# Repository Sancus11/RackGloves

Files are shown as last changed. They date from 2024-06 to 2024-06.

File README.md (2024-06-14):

# RackGloves

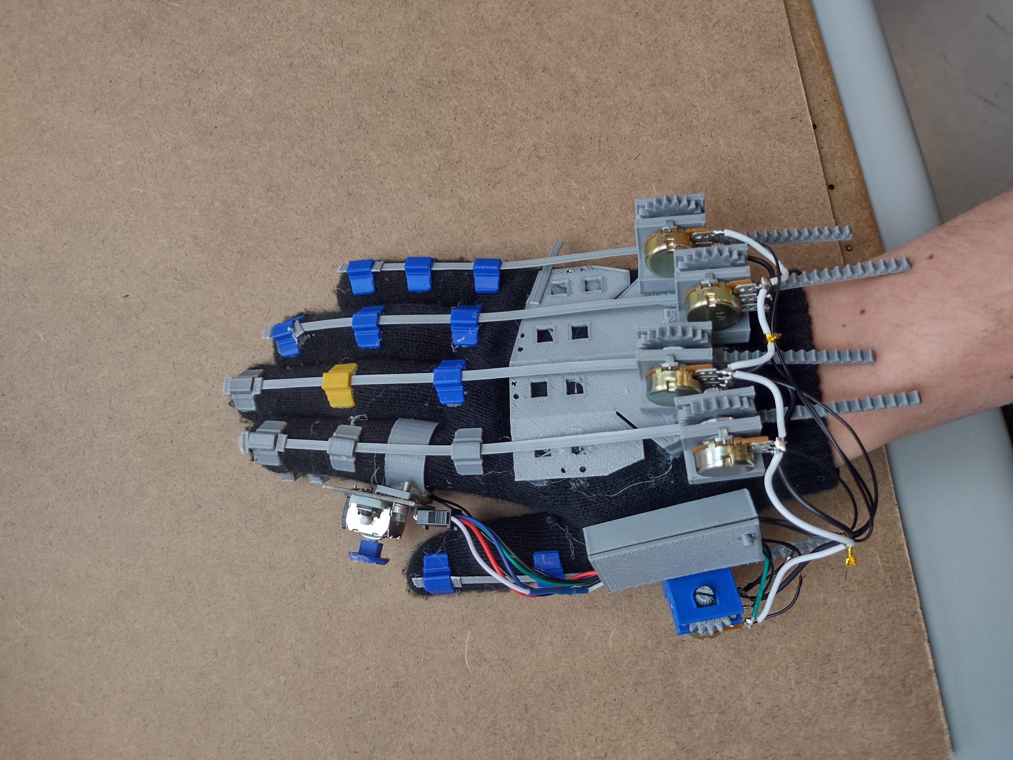
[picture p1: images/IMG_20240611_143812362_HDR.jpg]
image of the finished glove


Simple, cheap and, working glove harware for vr finger tracking using opengloves and lucidvr. This has the advantage of having the bare minimum of assembly and minimal parts that you may already have on hand. It works by a flexible strip on the back that has its horizontal motion actuate a rack on a pot. It uses version 3 of the software so tracking only. Only minimal assembly and parts needed.

Joystick ring mount, button mount, and esp32 case are also in this repo.

NOTE: things are currently in a beta state. May not work the best but it should get you from start to finish. Any improvements are welcome. See pull request for bata and incomplete additions 

# Build Guide

 We have a comprehensive [build guide](Build_Guide.md) and all the necessary stls here. Additional parts can be found from the [protoloves repo](https://github.com/Valsvirtuals/ProtoGlove) and from other [community designs](https://github.com/LucidVR/lucidgloves/wiki/Community-Design-List). 

# Software

Take the esp software from the [Lucidgloves repo](https://github.com/LucidVR/lucidgloves) and it will communicate with the [Opengloves software](https://github.com/LucidVR/opengloves-driver) for steam vr.

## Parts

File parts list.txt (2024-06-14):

for 1 hand
from proto glove
  1 thumb plate
  1 hand plate (modular)
  1 controller ring mount
  1 controller mount
  5 single point modular mounts

from this repo
for tracking fingers
rack units
  5 bodies
  5 racks
  5 fingerline
  5 spur gear
  14 guides (sewing or glue)

  non printed
  5 10k potentiometers

for espcase
  1 lid
  1 case
  1 button push

for buttons
  1 button baseplate
  2 button house

  non printed
  2 6mm pushbuttons 

for joystick
  1 joystick mount (may need adjusting)
  1 joystick ring (may need adjusting)
  1 joystick nub (may need adjusting)

  non printed
  5 pin female jst connector
  1 joystick unit

Needed tools to assemble
  Sandpaper
  3d printer
  Soldering station
  Wire
  hotglue
  Super glue
  Sewing thread and needle (optional)
  wd-40 
  Drill bits (optional)
  Twist ties

list of non 3d printed parts (duplicates in prior lists)
  2 6mm pushbuttons 
  5 10k potentiometers
  5 pin female jst connector
  1 joystick unit

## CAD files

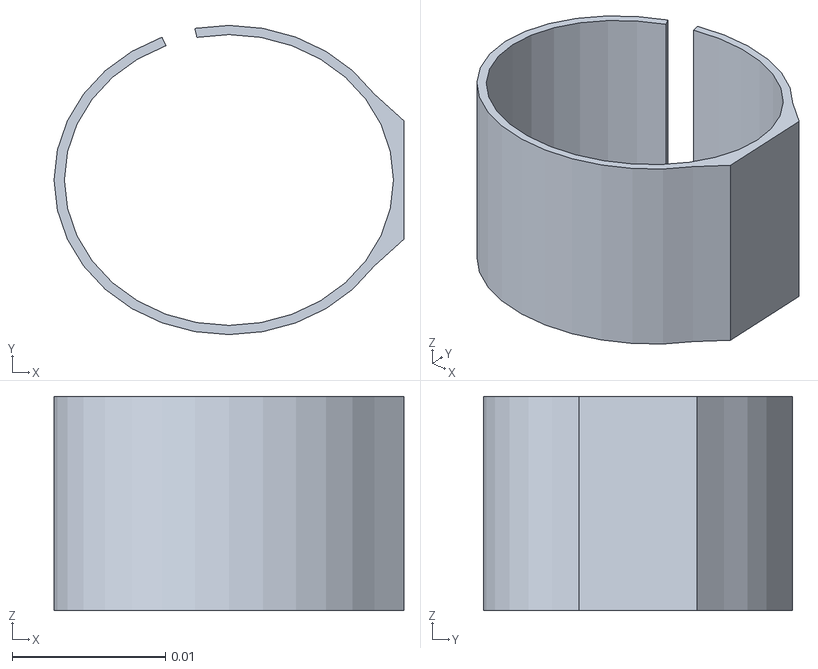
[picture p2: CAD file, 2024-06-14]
everything v1/controlls/joystick ring.stl
0.0229 x 0.0202 x 0.014

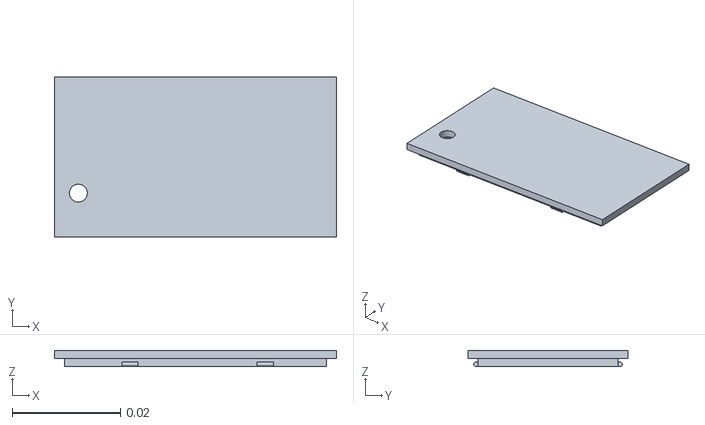
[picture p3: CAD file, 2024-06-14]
everything v1/espcase/lid.stl
0.052 x 0.0295 x 0.003

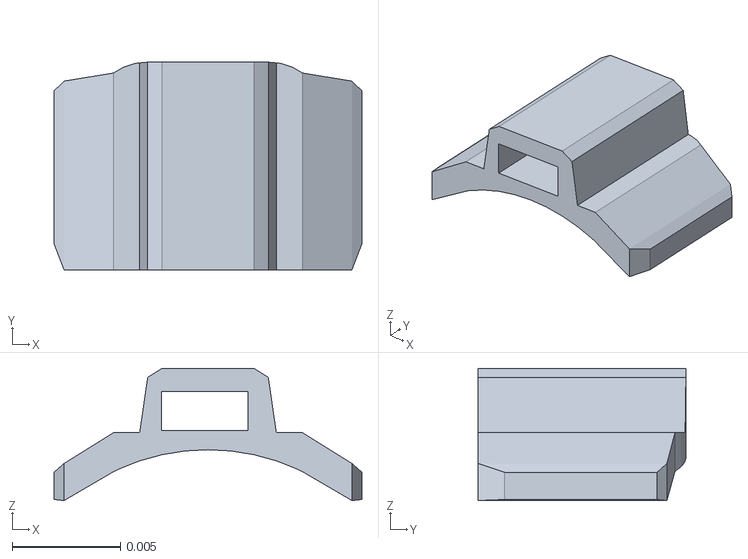
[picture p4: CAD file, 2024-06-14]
everything v1/guides/glue guide l.stl
0.0143 x 0.00961 x 0.00611

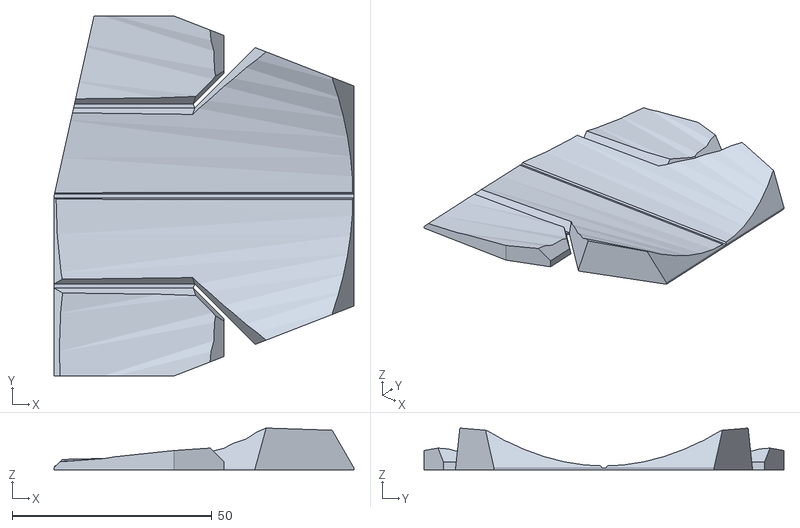
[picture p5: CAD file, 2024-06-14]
everything v1/proto gloves/P-B-5-B-G- glued/P-B-5-B-G-11-L.stl
75.0 x 90.0 x 10.5

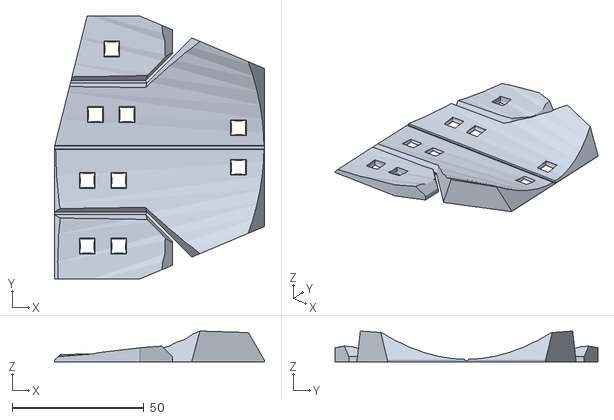
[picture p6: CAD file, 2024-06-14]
everything v1/proto gloves/P-B-5-B-M- modular/P-B-5-B-M-13-L.stl
80.0 x 100.0 x 11.8

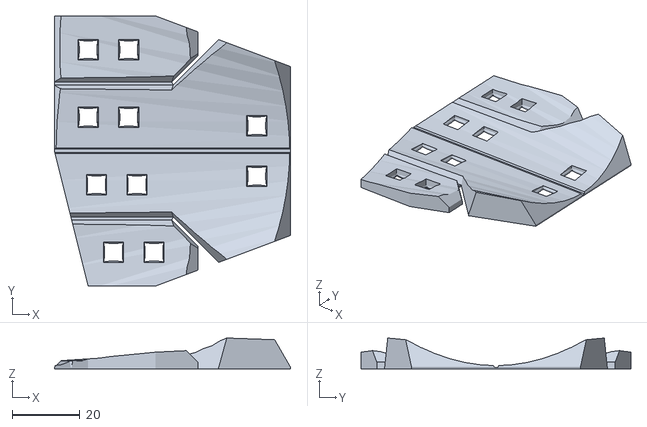
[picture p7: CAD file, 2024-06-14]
everything v1/proto gloves/P-B-5-B-M-09-R.stl
70.0 x 80.0 x 9.18

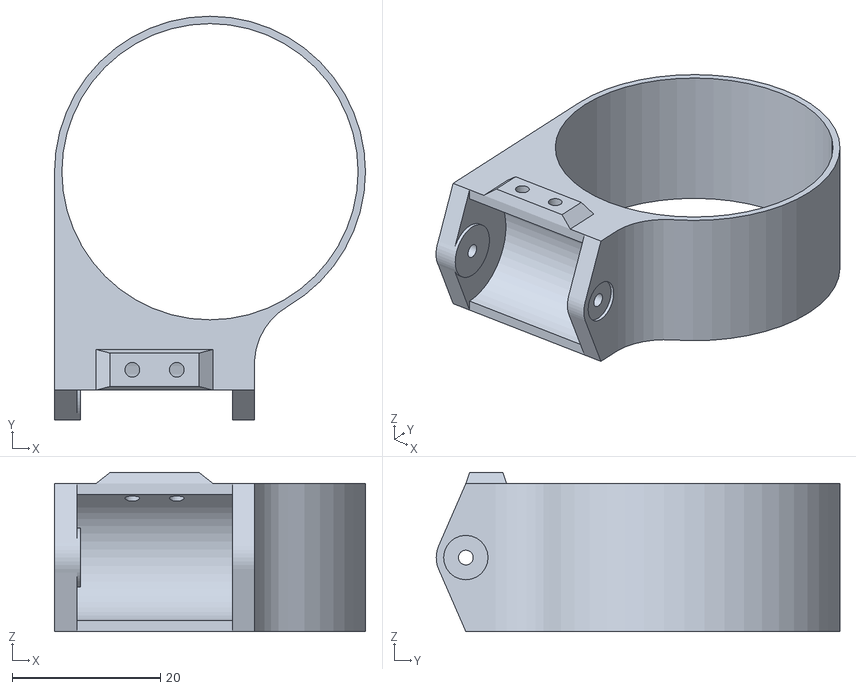
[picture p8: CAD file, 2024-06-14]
everything v1/proto gloves/P-C-Q- quest/P-C-Q-L.stl
42.0 x 54.5 x 21.5

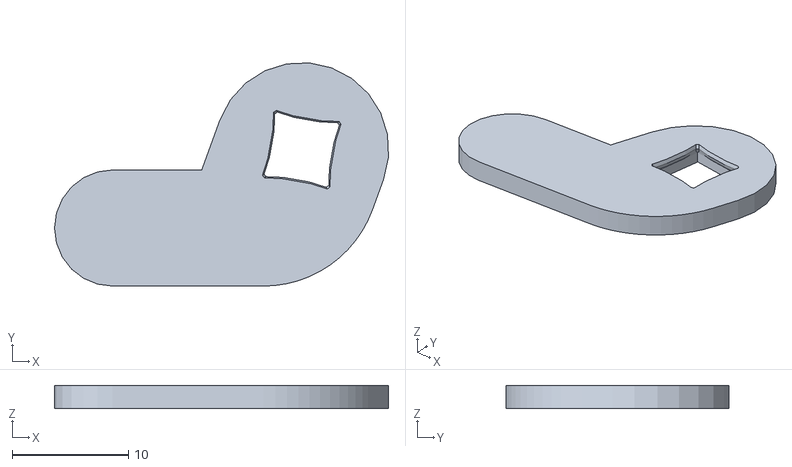
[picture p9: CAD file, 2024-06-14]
everything v1/proto gloves/P-T-M modular/P-T-M-12-L.stl
28.8 x 19.2 x 2.00

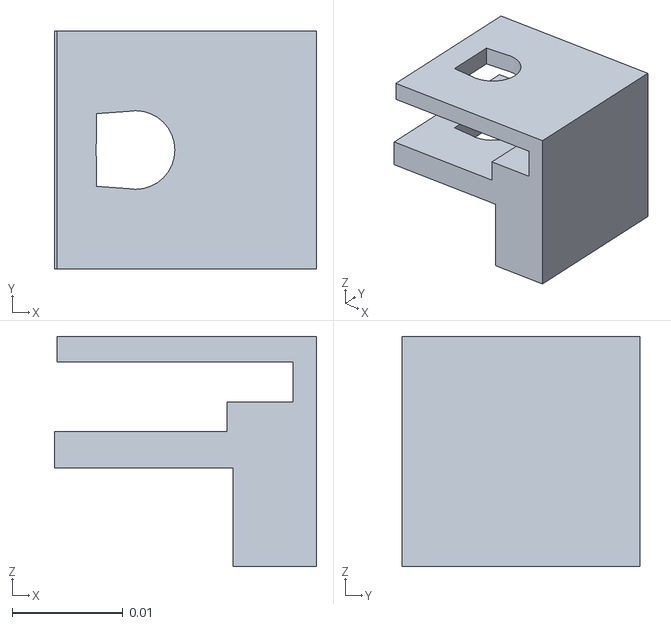
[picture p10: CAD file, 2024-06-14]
everything v1/rack unit/body.stl
0.0236 x 0.0215 x 0.0208

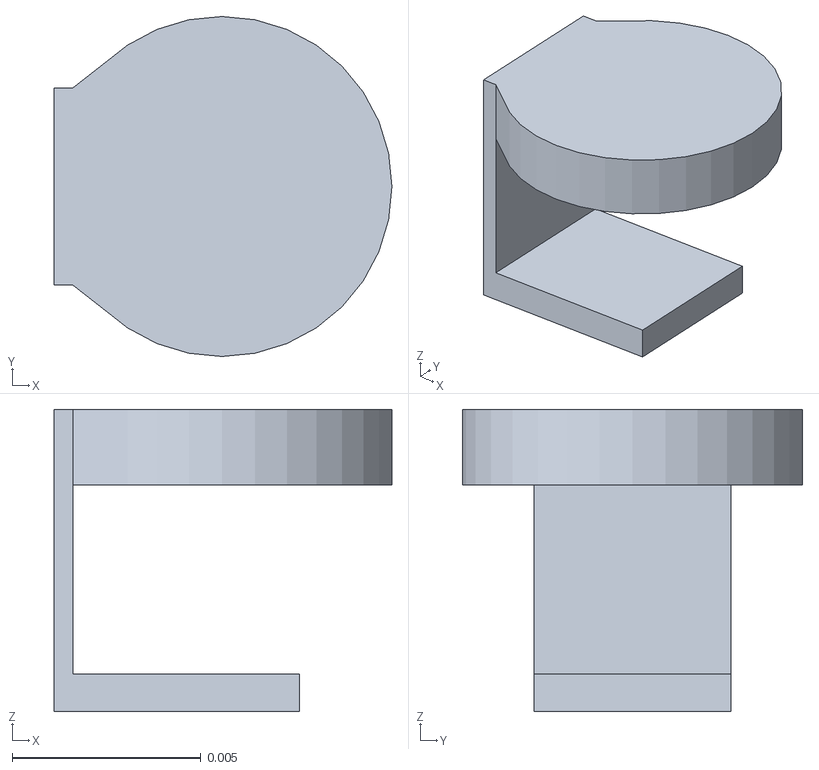
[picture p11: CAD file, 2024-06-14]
everything v1/controlls/button house.stl
0.00894 x 0.009 x 0.008

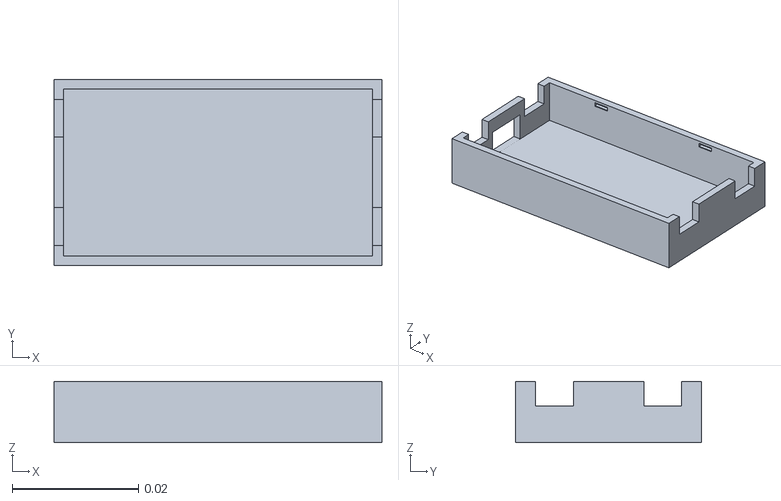
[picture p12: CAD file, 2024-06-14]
everything v1/espcase/case.stl
0.052 x 0.0295 x 0.0097

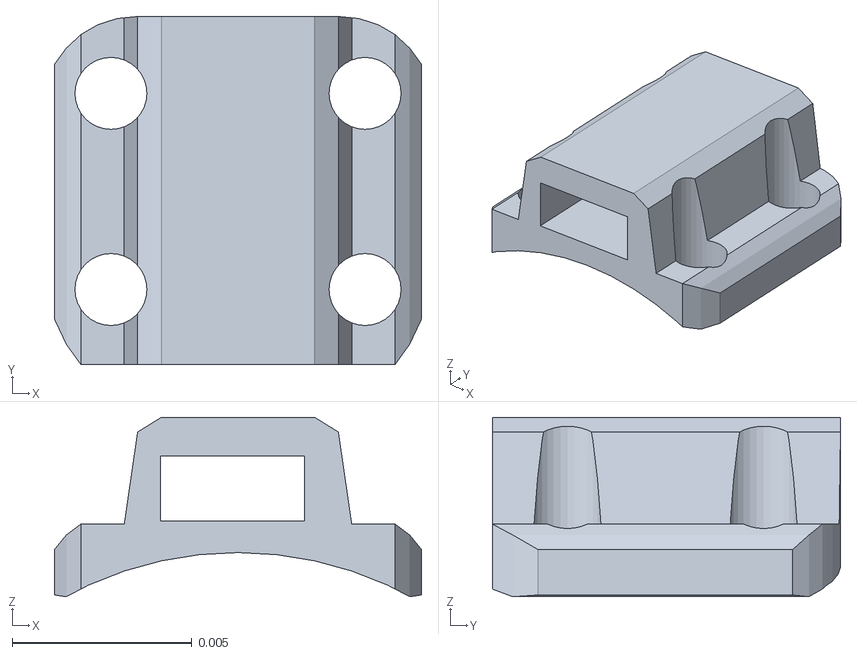
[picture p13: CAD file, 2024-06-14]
everything v1/guides/sewing guide.stl
0.0102 x 0.00967 x 0.00499

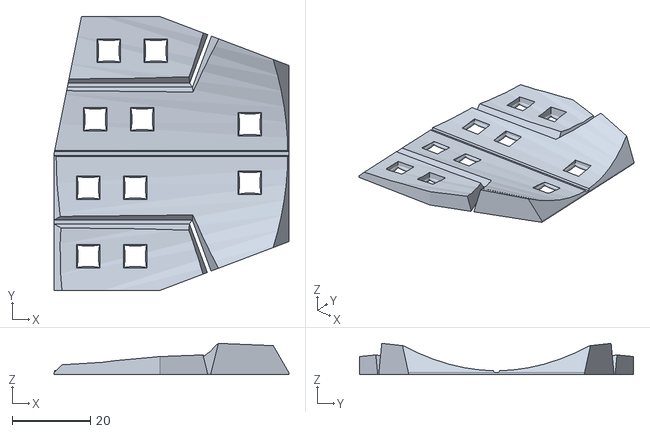
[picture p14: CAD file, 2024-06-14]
everything v1/proto gloves/P-B-5-B-M- modular/P-B-5-B-M-07-L.stl
60.0 x 70.0 x 8.00

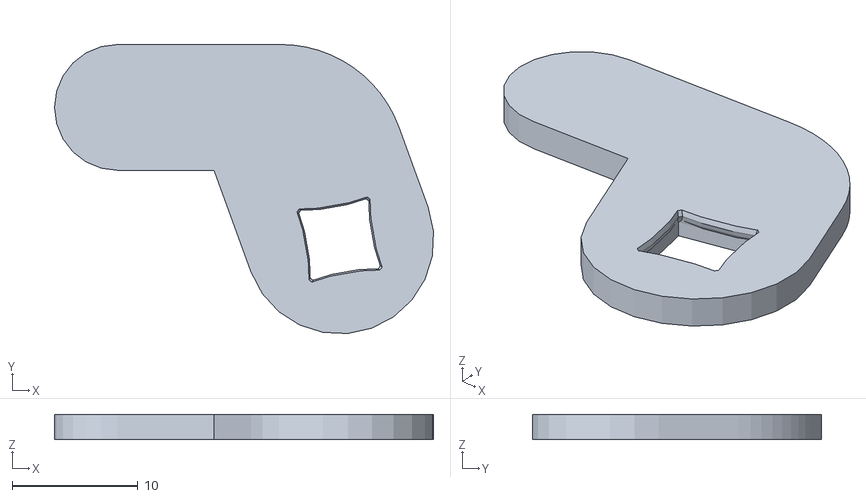
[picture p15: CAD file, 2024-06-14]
everything v1/proto gloves/P-T-M modular/P-T-M-16-R.stl
30.1 x 23.0 x 2.00

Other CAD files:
everything v1/proto gloves/P-B-5-B-G- glued/P-B-5-B-G-09-L.stl
everything v1/proto gloves/P-C-Q- quest/P-C-Q-R.stl
everything v1/proto gloves/P-T-M-24-L.stl
everything v1/rack unit/spur gear.stl
Rack-Gloves.blend
everything v1/controlls/button baseplate.stl
everything v1/controlls/joystick mount.stl
everything v1/controlls/joystick nub.stl
everything v1/espcase/button push.stl
everything v1/guides/glue guide m.stl
everything v1/guides/glue guide s.stl
everything v1/guides/glue guide xl.stl
everything v1/proto gloves/P-B-5-B-G- glued/P-B-5-B-G-05-L.stl
everything v1/proto gloves/P-B-5-B-G- glued/P-B-5-B-G-05-R.stl
everything v1/proto gloves/P-B-5-B-G- glued/P-B-5-B-G-07-L.stl
everything v1/proto gloves/P-B-5-B-G- glued/P-B-5-B-G-07-R.stl
everything v1/proto gloves/P-B-5-B-G- glued/P-B-5-B-G-09-R.stl
everything v1/proto gloves/P-B-5-B-G- glued/P-B-5-B-G-11-R.stl
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

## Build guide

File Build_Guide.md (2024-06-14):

# Build Guide

completed glove

# Parts

For this guide you will need to print various parts found in this repo and in the protogloves repo. A print list file is provided and a copy of protogloves can be found in this repo. A list of tools needed are also included. The only non printed parts are an esp32, 5 potentiometers, pair of gloves (stretchy magicgloves recommended) and an optional joystick and 6mm pushbuttons.

It took me about 6 hours to build the second glove while making this guide. Also about 160 g of filament and 18h of printing. 

I recommend using the glued version as it is faster to make. I also recommend using stretchy magicgloves or similar glove.

image of all parts and materials. sandpaper and sidecutter not included

## Printing

All parts have a sensible orientation to be printed without supports. Default settings on a 0.4 mm nozzle work. I recommend a raft on all parts. If printing the glue guides print mostly the XL guides as they glue the best

## Tools 

You will need superglue, hotglue, sandpaper, needle nose pliers, wd-40, soldering station, wire and  twist ties(for cable management). A sewing needle and thread are needed for the sewn guides as well as drill bits for creating holes to thread in the 3d printed parts(or you could modify the stl. I would appreciate a pull request with those)

# Build Guide

## Making the Rack Units

### Lubricate the Potentiometers

Resistanceless operation of the potentiometers is required for the gloves to work. 

Lay down a paper towel to catch drips. Spray WD-40 into the top of the potentiometer and spin back and forth to work it in. Repeat until it spins freely and for each potentiometer.

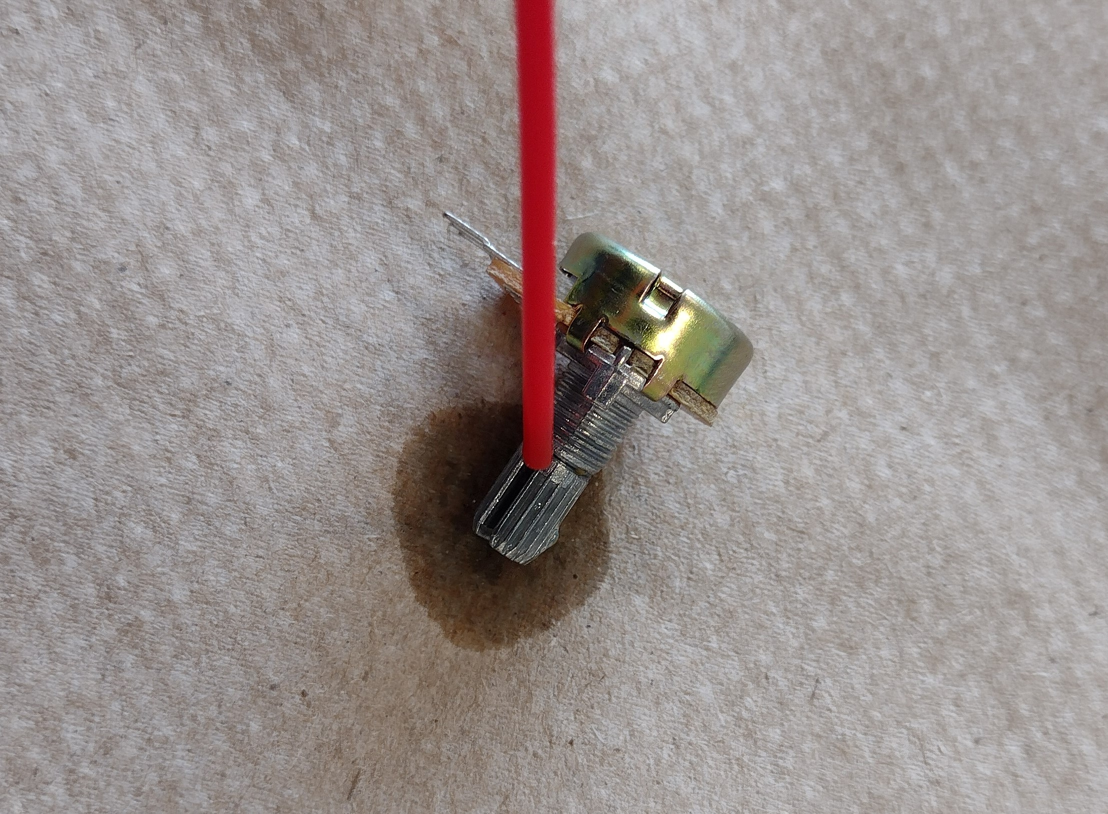
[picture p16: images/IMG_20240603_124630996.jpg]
Lubricating pots


### Glue Racks and Fingerline

Sand the end of the rack and the Fingerline to prep for superglue.

Apply a dab of superglue to the slot on the rack and press the end of the fingerline onto it. Make sure it is straight and you are gluing the slightly more narrow end of the fingerline to the rack

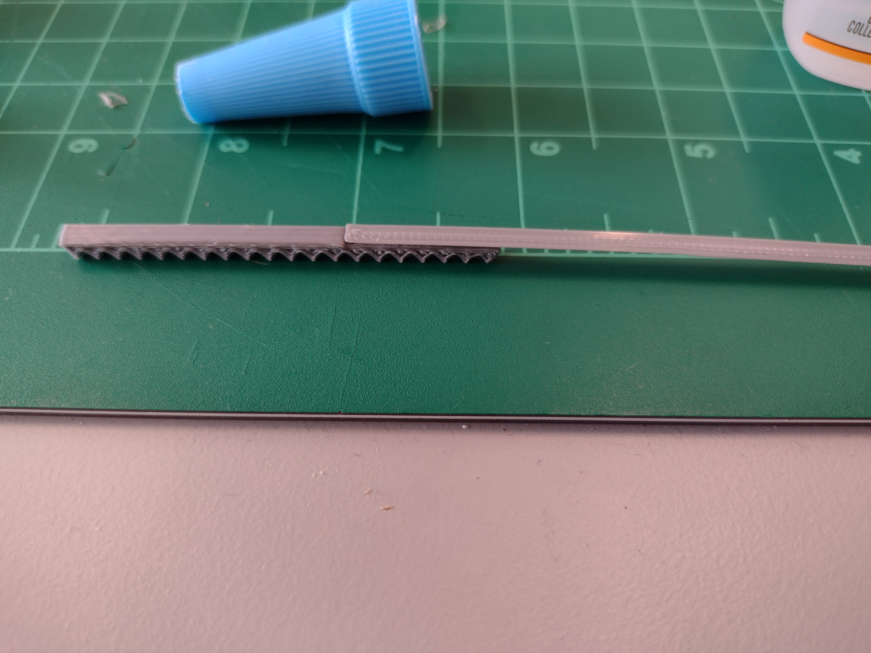
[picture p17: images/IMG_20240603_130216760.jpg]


Sand the edges and sides of the new rack unit to ensure it slides smoothly. More sanding or a reprint may be needed if tolerances were poor but that is unlikely

### Assemble the Rack Unit

Note: the potentiometer can sit in 2 positions allowing you to mirror it for a cleaner final product. 

Insert the potentiometer neck through the unit body. It should skew the gear and locking nut included with your potentiometer. Take care that the gear is oriented correctly when doing this or it will not fully insert. 

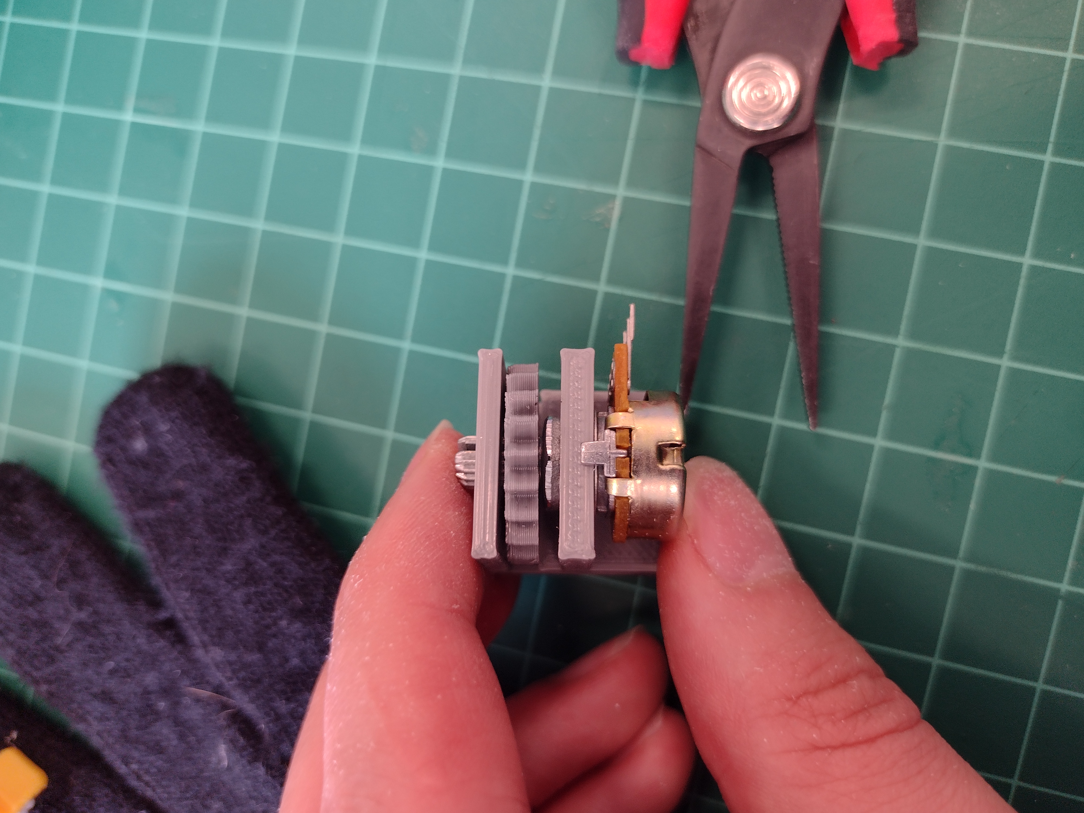
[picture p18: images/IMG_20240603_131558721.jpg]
properly skewed assembly


Start threading the nut on but do not tighten it yet. It should be just barely on so that you can still rotate the potentiometer body free of the unit body.

Rotate the potentiometer fully counterclockwise and rotate the potentiometer body by 45 degrees counterclockwise relative to the rack unit

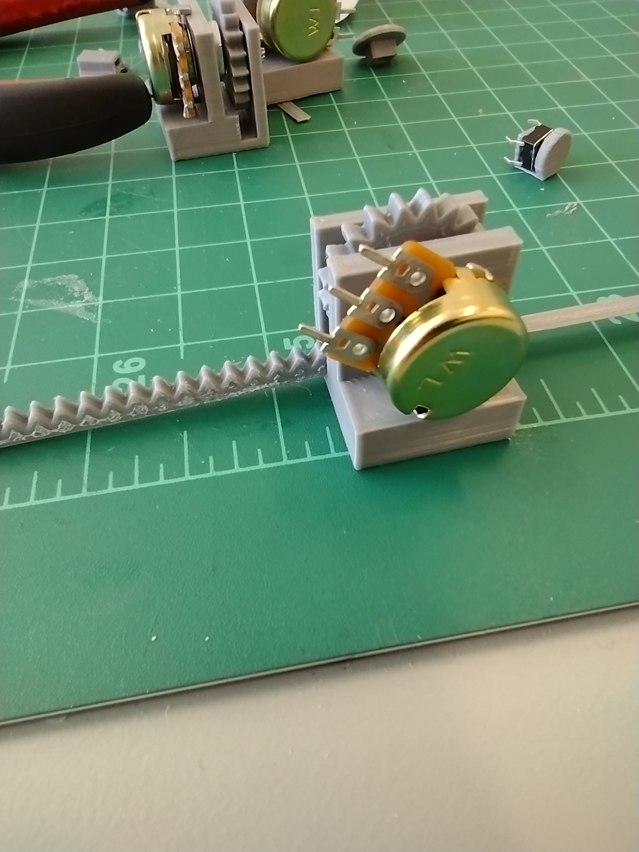
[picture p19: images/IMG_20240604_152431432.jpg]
in ready to insert rack position


Insert the rack into the body and rotate the potentiometer into the seated position. Tighten the nut using the pliers. If assembled correctly the Fingerline will be sticking out the opposite side of the connectors and the potentiometer will stop rotating before the rack falls out. Make sure it moves freely and sand if necessary.

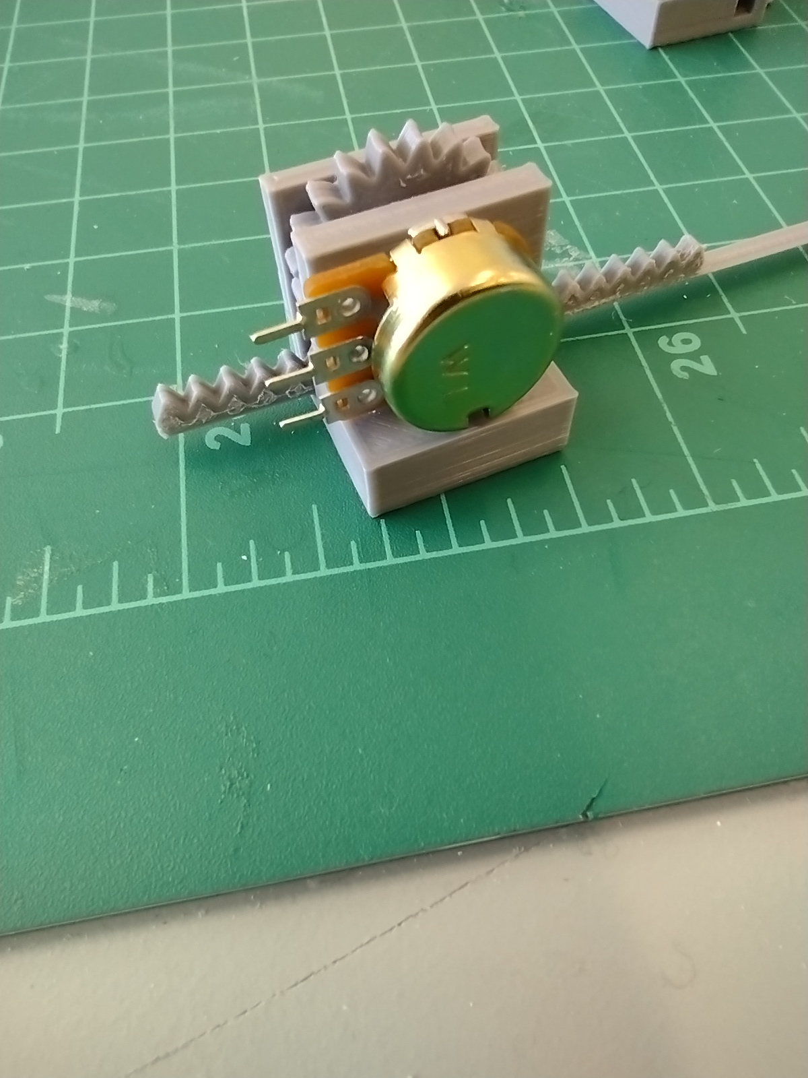
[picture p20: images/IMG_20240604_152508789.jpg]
finished unit


## Attaching Mounts

There are 2 ways to attach the mounting hardware. One is hotgluing it to the glove. This is fast and permanent. The other is sewing them on. This takes some more time but can be removed. I recommend gluing as it is fast and the Fingerline guides and proto glove parts make it easy to still repair and modify.

## Gluing

It is important to apply the guides while wearing the glove so that it aligns properly. You also only get one shot to apply it.

While wearing the glove find a good position for the mounting plate and mark it (use tape or marker). Apply a thick hot glue line to the back of the mounting plate taking care not to add to where mounting holes or joints are(see image for recommended placement). Lay and press the mounting plate onto the glove while wearing it. Make sure the glue is hot and it is properly aligned as you only get one shot. 

marked glue locations

While wearing the glove find the appropriate size of glue guide for each finger. Xl for most fingers, possibly L for the pinky. Apply a thick bead of hot glue to the back and press onto the top of each finger equal distance from each joint. Make sure it is straight and in the middle as you only get one shot. I recommend putting the bottom joint on the index finger a little lower to not interfere with a joystick ring. 

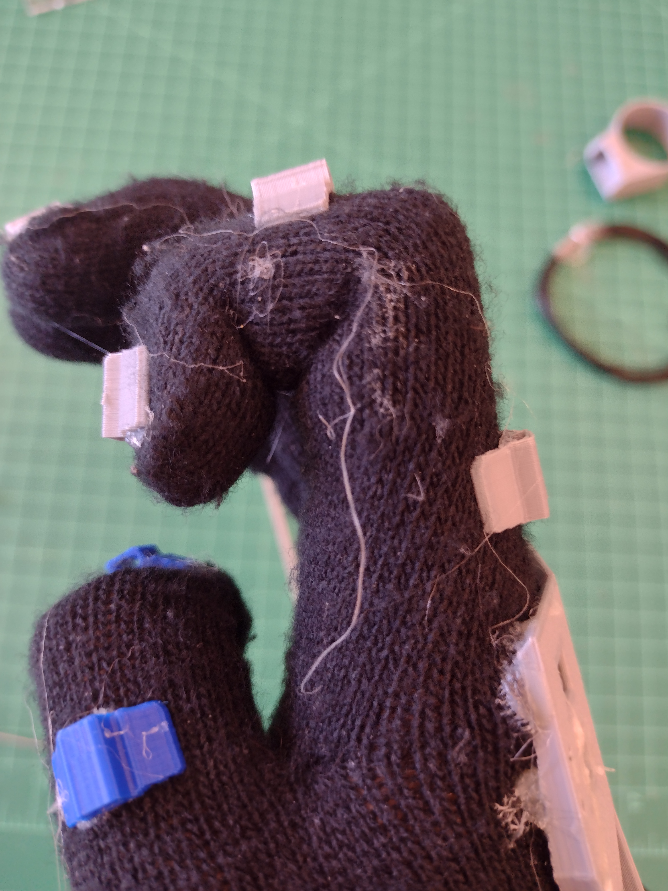
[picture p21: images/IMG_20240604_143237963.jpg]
correct layout of locations


Apply a bead of hot glue to the thumb plate and press in place like the main mounting plate.

## Sewing

Sewing on the guides while wearing it is recommended to align it properly (I know one handed sewing is a pain).

Drill out holes in the required places (see images)

hole locations

Sew the guides in place while wearing. The guides should be in the center between two joints. I recommend putting the bottom joint on the index finger a little lower to not interfere with a joystick ring. 

## Mounting the Hardware

Sand the front of the glove mounting plate, back and front of plate modules, and the bottom of the rack unit to prep them for gluing.

### Attach the plate modules

Apply a tiny amount of superglue to each of the plate modules on the bottom and around the snap connector. This glue will stop them from coming loose but can be broken with some prying. 

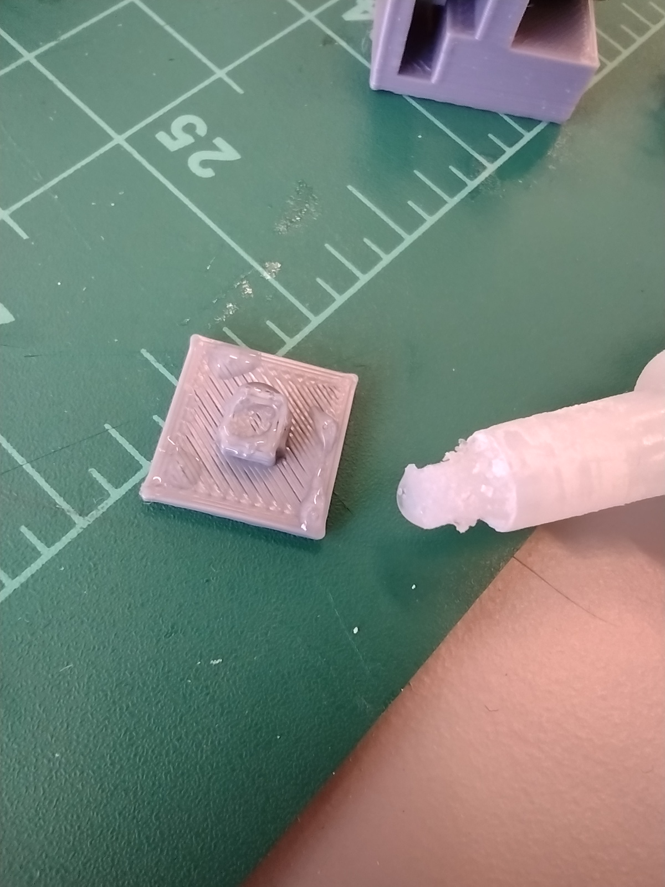
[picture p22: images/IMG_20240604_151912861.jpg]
glue on mounting plate


Snap each one in place on the back row of mounting points. Trimming the edges of a couple may be needed to get them to fit.

atached mounting plates

### Attaching the Rack Units

While wearing the glove push a fingerline through all of the guides and see what rotation it naturally wants to sit at. Experiment with mirroring it so that they all can fit side by side without much bending or overhang. Once you find a good position mark where they sit on the mounting points and apply superglue to fix them in place. Some overhang is fine. Below is an example of a “good” layout(I accidentally pushed them back too far towards the wrist so move them forward a little bit yourself) 

ligned up fingerlines

### Setting Finger Length

To fix the end of the fingerline to the end guide 

Push the rack to the fully retracted position and bend your finger backwards to fully extend it. Trim the end of the fingerline flush with the end guide. Keep the trimmings(I did not cut flush in the image. my bad). Repeat for each finger. 

I messed up

Add a peice of trimming to the pinky side to stop the fingerline from sliding over the edge

added guide

Take off the glove and sand the top face of the fingerline and the trimming to prep for gluing. Cut the trimmings into small lengths just a little longer than they are wide. Superglue the trimmings onto the end of the fingerline to serve as a stop. Superglue more trimmings onto the other side of the end guide to serve as a stopfor that end. These trimmings can be twisted off without issue for easy replacement.

glued endstops

### Attaching Esp Case

Sand and superglue the esp beside the thumb. Make sure the usb port is down. Make sure the lid fits. You may need to drill the button hole larger or wrap tape around the bottom of the button to increase diameter so it does not fall out.

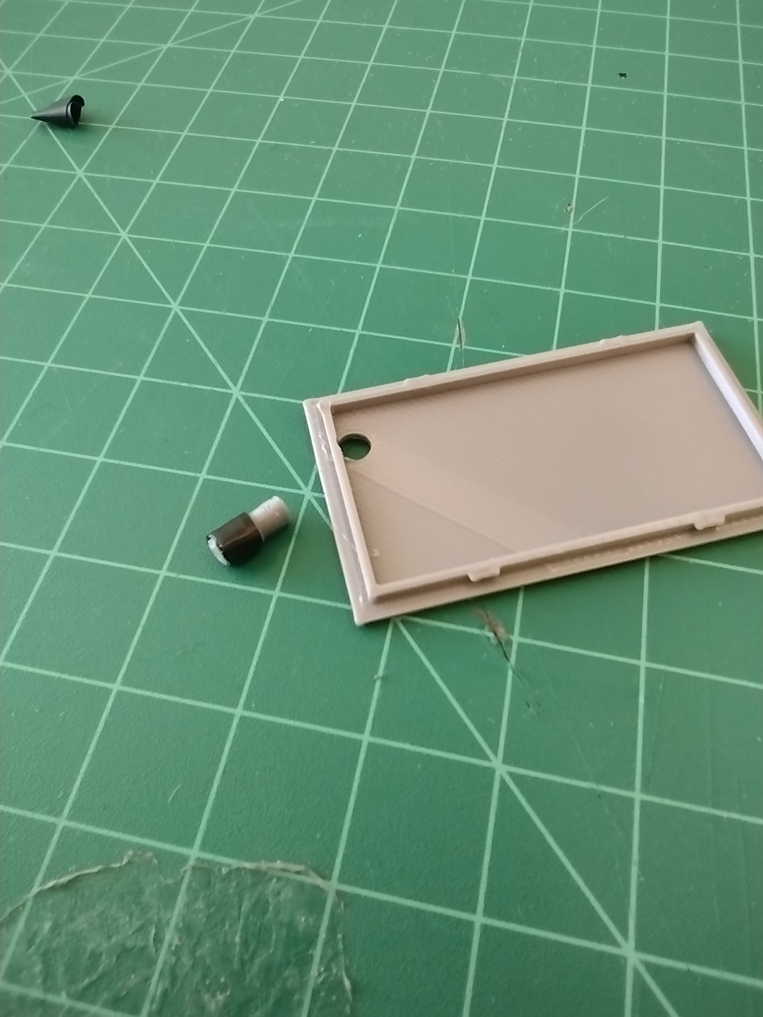
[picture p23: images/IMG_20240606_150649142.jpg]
modified button insert


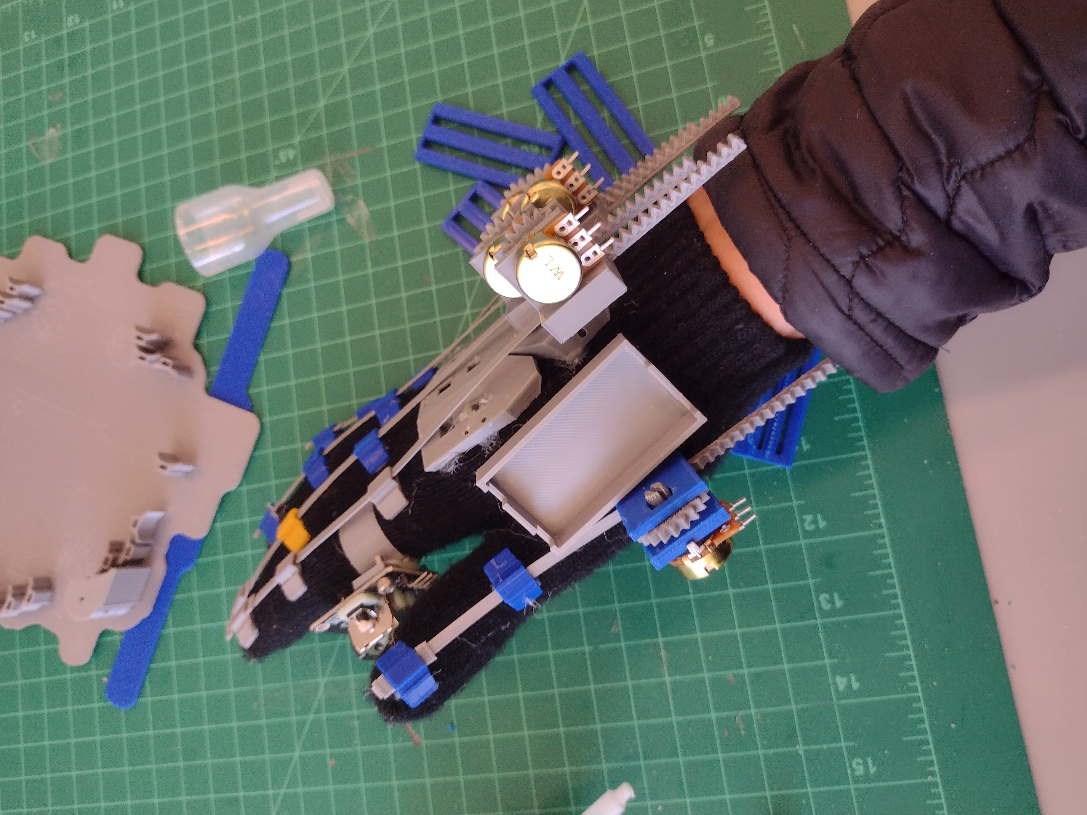
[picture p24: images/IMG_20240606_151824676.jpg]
attached esp case


## Buttons

Apply a dab of superglue to the button bottom and attach  to the housing

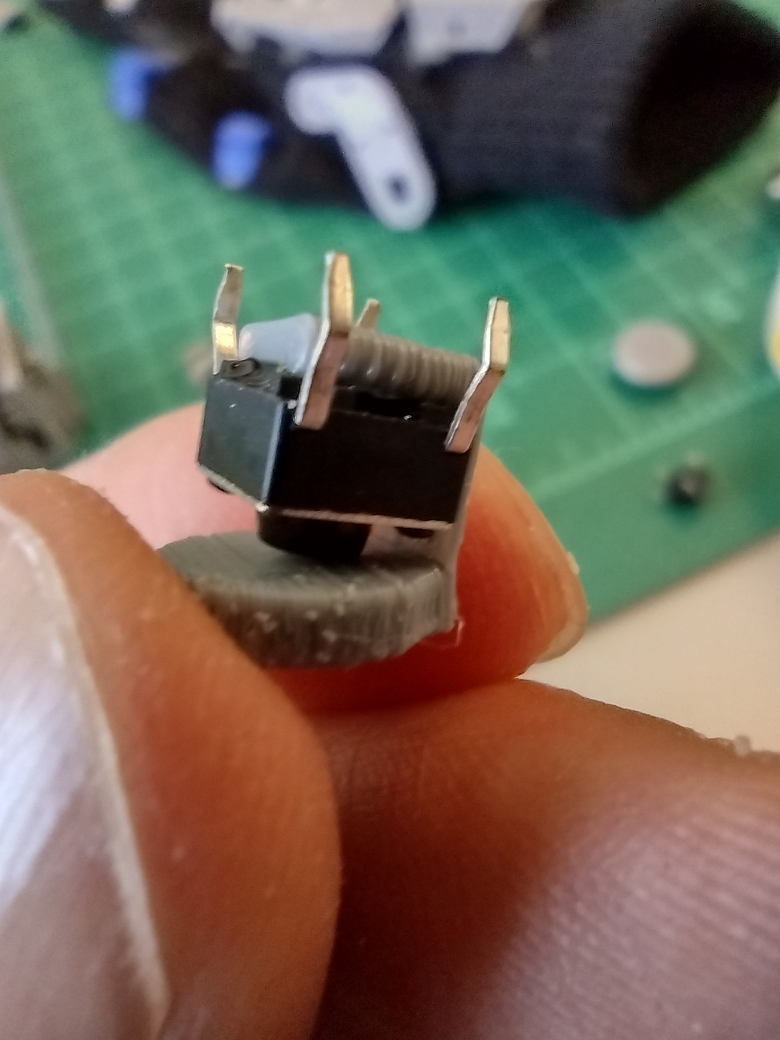
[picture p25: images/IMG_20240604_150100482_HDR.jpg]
superglue on button


Hot glue or sew the mounting plate to the end of the index finger. It should be slightly towards the bottom but you can find where is comfortable. I sewed it for convience

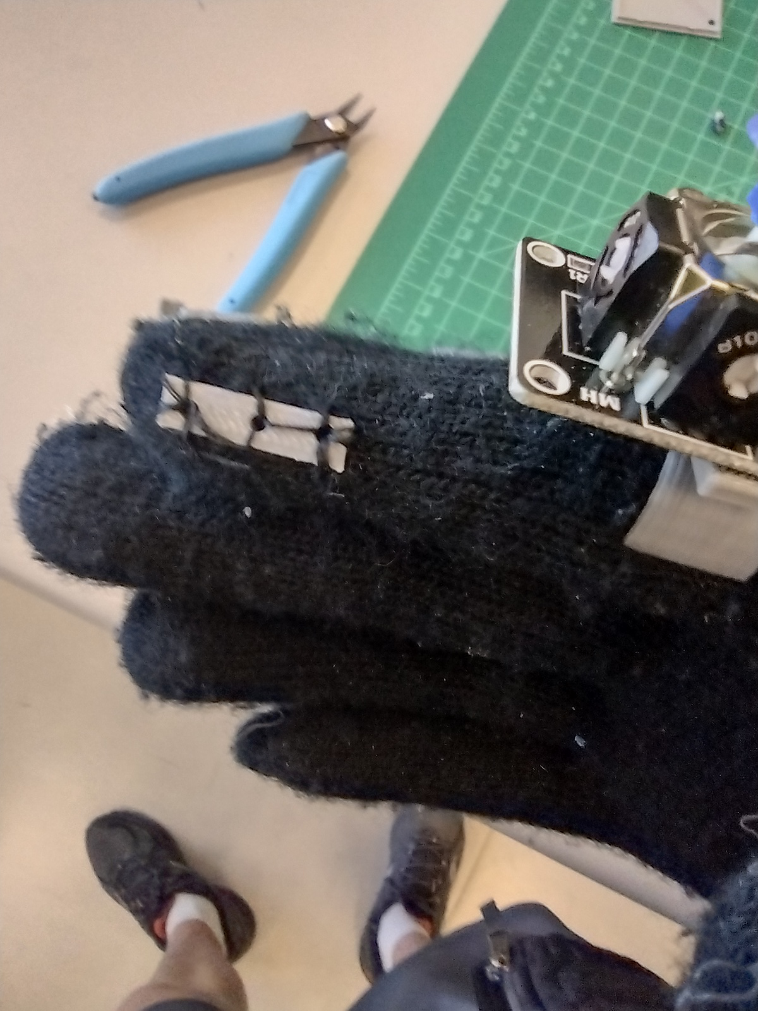
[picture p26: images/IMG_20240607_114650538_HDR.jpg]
attached mounting plate


Superglue the buttons to the plate. The open end should be towards the thumb.

attached buttons

## Joystick

Use 8mm 3M screws to attach the joystick to the mounting plate or glue it. It is recommended to attach it to the holes closest to the pins. Slide the controller ring onto your index finger. The gap should be on the bottom of your hand and the flat part should face towards your thumb. You can rotate the gap around the mounted fingerline get it to fit. Hot glue the joystick to the controller ring so that the pins are facing down towards your palm. Add a small dab of hot glue on the side of the joystick rod and insert the new joystick on top(the shorter joystick makes it more comfortable). Coat the top of the nub in hot glue to make it gripy. pictured is a right joystick

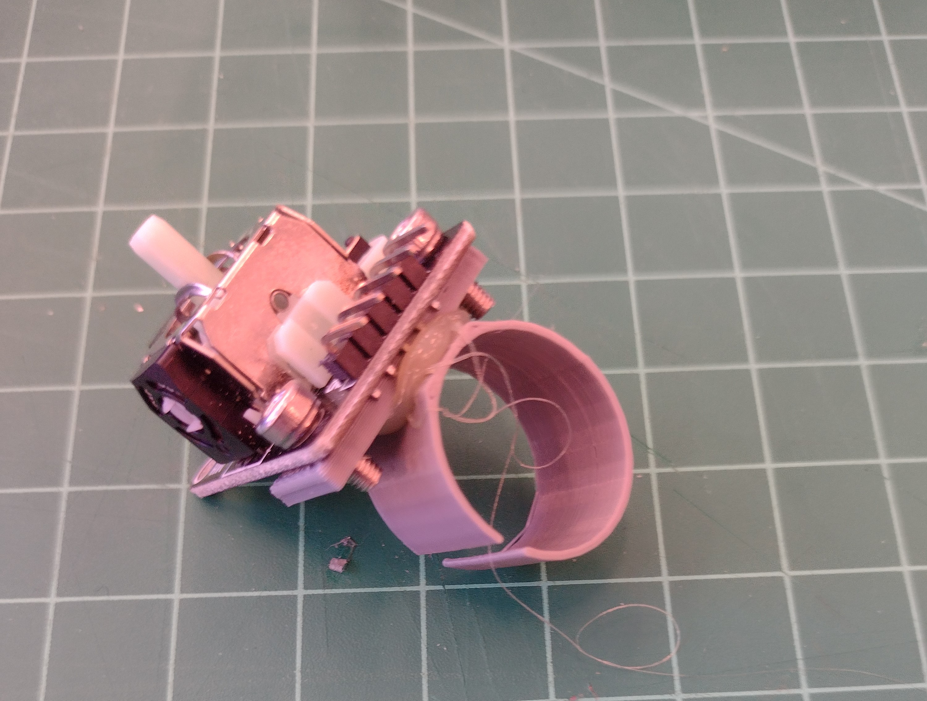
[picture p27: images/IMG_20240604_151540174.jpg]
mounting of a right joystick


# Wiring

Wire the potentiometers all positive to the top and negative to the bottom. Wire the thumb potentiometer to the esp vcc and ground Attach a wire to the output of each potentiometers that is long enough to reach the esp32. Moving your thumb and hand to test this length in all positions.

positive and negative wired pots

For the joystick it is recommended to use a pre-crimped jst connector to wire back to the esp and have it share vcc and ground with the potentiometers.

The buttons can be wired by leaching a ground off of the joystick. Solder a wire to one the mounting pins on the joystick and to a button. Make sure there is enough wire when your finger is curled and extended. Solder the two push buttons together to share a ground. Run a wire from each button back to the esp32. Make sure there is enough wire when the finger is bent and extended. Add a wire guide to the joystick to help keep the wires in check. In the example I have created a wire gap for routing by making a hot glue bridge. Glue down the solder joints to prevent them from wearing and snapping during use. 

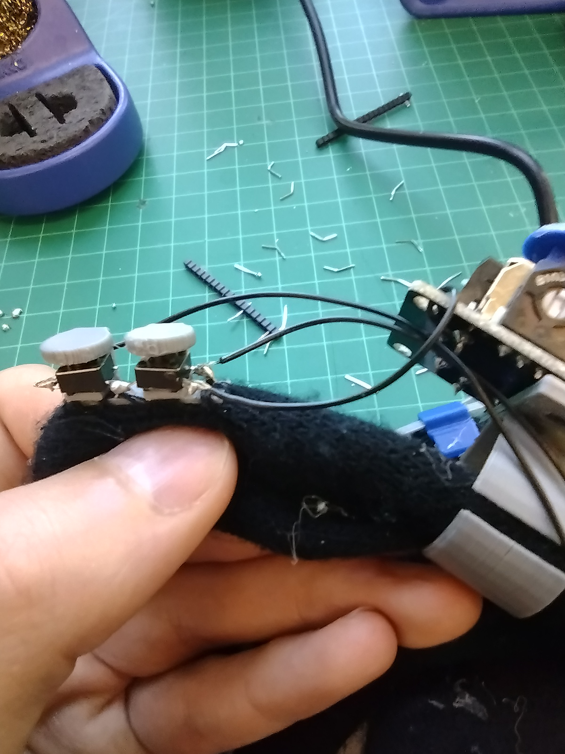
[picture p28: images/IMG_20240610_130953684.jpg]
soldered buttons

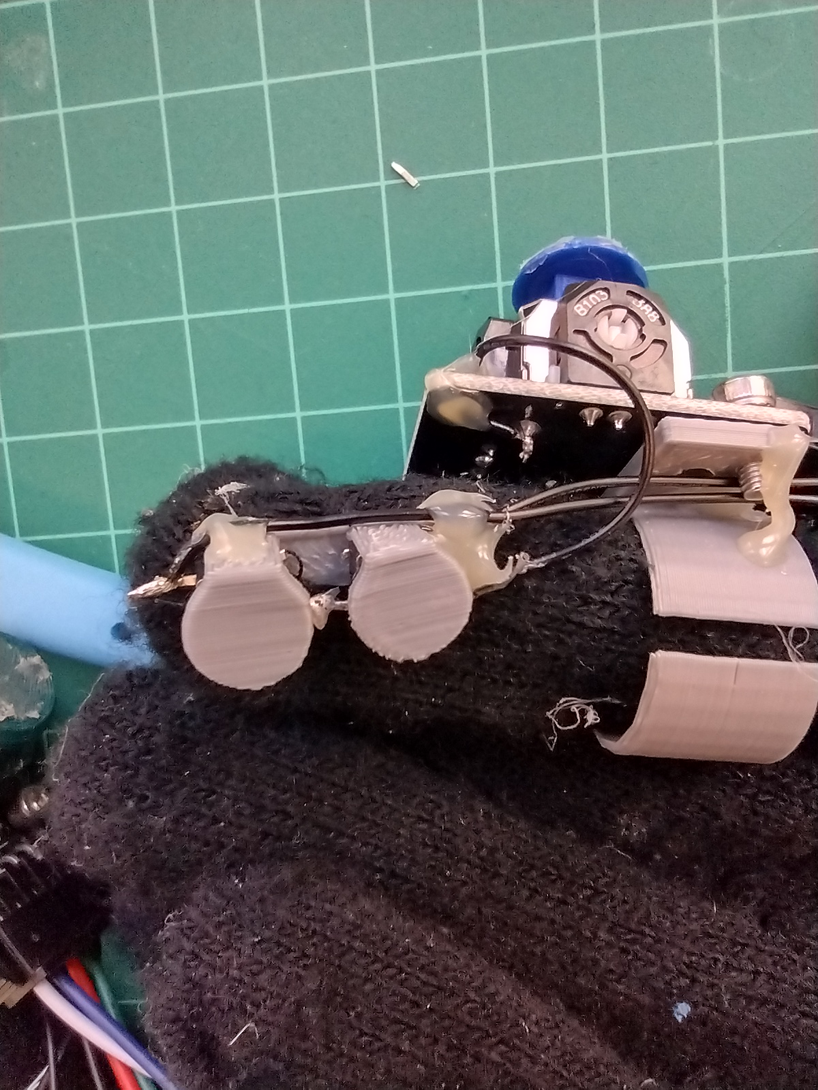
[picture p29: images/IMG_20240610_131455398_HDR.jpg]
glued buttons

wired glove

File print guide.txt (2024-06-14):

standard quality
default settings
no supports
.4 mm nozzel recomended
raft is recommended for all parts execept protoglove parts
reduce print speed to 15mm/s for the rack and gears
all parts have a sensable orientation 
some parts sizes specified in meters. please ajust as needed

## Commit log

2024-05-30 Create print gide.txt
2024-06-11 Update print gide.txt
2024-06-11 Rename print gide.txt to print guide.txt
2024-06-11 Rename trying to fix zip line.blend to Rack-Gloves.blend
    [Rack-Gloves.blend]
